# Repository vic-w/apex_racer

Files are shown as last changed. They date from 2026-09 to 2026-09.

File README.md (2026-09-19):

# APEX GT-01 双座公路跑车

当前 CAD、STEP、STL 和 3MF 均已缩为原设计的 **60%**。切片软件保持 **100%** 导入，**不要再缩到 60%**。

侧放打印尺寸约 **119.7 × 32.4 × 56.4 mm**，小于 [A1 mini 的 180 × 180 × 180 mm 成型空间](https://us.store.bambulab.com/products/a1-mini)。3MF 是通用网格文件，不含打印机切片参数。

## 座舱、车窗和尾翼

- 主车身重新绘制为平顺的三次样条曲面，控制机盖与轮拱的高差，避免局部鼓包及深凹槽。前舱和后部的 14 条纵向采样线均无额外波谷；机盖与轮肩最大高差约 **2.12 mm**。
- 车头与车尾向端部渐降，最前、最后的底缘以相切曲线上收，减小厚重的垂直立面。端部中心截面厚度约为车头 **5.9 mm**、车尾 **6.2 mm**；前脸采用单层宽进气口。轮拱与贴床区不随端部一起压扁。此项为外形调整，未进行风阻仿真。
- 两个前大灯分置在车头左右外角，灯带跨越机盖上表面、前脸与侧面，在圆角处连续转折。每侧灯面均实测覆盖这三个面；侧面灯尾位于输出坐标约 **Y=±28.1 mm**。边框投影宽 **0.54 mm**、沿包角三轴凹深 **0.39 mm**，灯罩面凹深 **0.11 mm**；边框和灯罩的高差可在单色打印中保留轮廓，全部与车体连为一体。
- 前后四角改为渐变弧线收拢，纵向退让 **7.2 mm**、横向过渡 **14.4 mm**，保留 **56.4 mm** 的最大车宽。圆角在侧放方向逐层外扩，最大坡度控制为 45°。
- 车顶使用沿车长放样的圆弧截面，前后和横向均有弧度，最高点约 **32.4 mm**。
- 四个轮拱覆盖胎面上方，车轮保持转动间隙；沿胎宽和上部 120° 圆弧采样，壳体最薄约 **1.78 mm**，与胎面径向间隙 **0.9 mm**。
- 座舱后部延长为缓降的溜背曲面，逐渐接入后轮肩部与尾部平台，避免后风挡末端突然下落。
- 侧窗从靠近贴床面的外侧肩部起步，向车顶按约 **45°** 内倾；侧放后也是与热床约 45° 的斜面。中部窗下缘距热床约 **0.5 mm**，上部横向宽度约 **43.4 mm**，兼顾逐层成型和双座比例。
- 前后风挡、门窗和新增后侧小窗扩大了玻璃区域，保留连续的窄 A 柱、B 柱与 C 柱。报告记录各窗凹面之间的最小间距。
- 两侧固定车门带真实门缝和凹槽把手。门缝宽 **0.54 mm**，侧窗凹面和门缝横向切入 **0.48 mm**。
- 尾翼采用有弧度、后掠及向两端收窄的曲面翼型，配合翘起的后缘、短支柱和端板，最高点约 **29.4 mm**。翼面后缘厚 **0.96 mm**，端板与支柱名义厚 **1.2 mm**。端板内侧经 **4.8 mm** 翼展长度渐变连接翼面，避免侧放时突然伸出平板。
- 座舱按两个并排乘员参考包络检查：座位中心间距 **18 mm**、坐垫参考宽 **16.2 mm**，保留躯干、头部和腿部参考尺寸。检查仅用于外观比例，模型内部未制作座椅或驾驶设备，车门不可开启。

预览及 FreeCAD 中的深色玻璃、深色灯框和浅色灯罩是实际几何面的显示配色。单色 STL/3MF 不含透明玻璃或多色材料。预览采用实际 CAD 面的法线，保留真实曲面和特征边界，避免平整面被错误显示成凹陷。

## 前后贴床区域

前保险杠与后轮后方车尾永久加宽，两侧外缘与轮面同处一个侧放打印平面，无需拆除辅助片。

| 检查区域（输出坐标） | 实际平面贴床面积 |
| --- | ---: |
| 车头 X=48 至 60.3 mm | 约 76.3 mm² |
| 车尾 X=-60.6 至 -48 mm，Z<22.8 mm | 约 69.0 mm² |

车尾统计排除了车轮和尾翼，单独检查后保险杠。尾翼端板也接触同一打印平面，具体平面面积及 0.20 mm 首层平均截面积见验证报告。

`print_in_place/bed_contact_preview.png` 中，灰色为整车投影，绿色为车身首层，深灰色为轮组首层，黄色为前后保险杠的平面接触区域。

## 一体打印与检查

模型包含三个互不粘连的实体：一体车身、前轮组、后轮组。同轴左右轮一起转动，前后轴独立转动。

- 只导入 `print_in_place/apex_racer_side_down.stl` 或 `apex_racer.3mf`，保持侧放朝向和三个实体的相对位置。最低点已在 Z=0。
- 输出轴径 **5.4 mm**、孔径 **6.6 mm**，径向间隙 **0.6 mm**；轮胎与轮拱径向间隙 **0.9 mm**。这些间隙随整体同比缩放。
- 可从 0.4 mm 喷嘴、0.16–0.20 mm 层高、3 圈壁、15–20% 填充开始切片。检查首层门缝、轮面纹路和轮组间隙，避免象脚连住活动件。
- 按侧放无支撑目标设计：侧窗约 45°、车顶逐步收拢、前脸开口以 45° 收口，尾翼端板渐变展开，支柱及轮毂也采用斜面。门缝和把手的浅凹槽仍有短距离桥接；关闭支撑后检查这些细节的逐层预览，保持轮轴活动间隙通畅。附着不足时可给保险杠及尾翼端板增加外侧 brim。

`scripts/check_delivery.py` 检查保存的 CAD 实体、两侧大灯在上表面、前脸和侧面的连续覆盖、主曲面平顺性、四角收拢、前后端部厚度及渐薄截面、四轮上方壳体覆盖、后座舱过渡坡度、座舱弧面与宽度、双座参考包络、门缝、前后贴床面、尾翼、打印尺寸及 STL/3MF 一致性。生成脚本检查两根轴完整旋转包络与车身的间隙。

尚未实物试打；几何检查不能保证特定材料和打印机上的免支撑效果及转动手感。

本地 Bambu Studio 2.2.1.60 已使用 A1 mini / 0.4 mm 喷嘴、Generic PLA、0.20 mm 层高、3 圈壁及 15% 填充关闭支撑试切片，共 282 层。报告保存 STL 校验值，确认切片所用的就是当前模型；试切片产生的 G-code 仅用于本地检查。

## 文件与重新生成

- `apex_racer.FCStd`、`apex_racer.step`：60% 尺寸的直立 CAD 模型。
- `apex_racer.3mf`、`print_in_place/apex_racer_side_down.stl`：同尺寸的侧放打印模型。
- `apex_racer_preview.png`：前侧透视、侧视、后侧透视及俯视预览。
- `print_in_place/validation_report.json`：所有尺寸均以输出文件为准。
- `scripts/build_print_in_place.py`：构建、缩放和几何检查。
- `scripts/body_surface.py`：平顺主曲面、四角弧线以及曲面检查。
- `scripts/headlights.py`：环绕前角的前大灯、浅凹边框以及三面连续覆盖检查。
- `scripts/sports_coupe.py`：弧面座舱、窗面、车门、曲面尾翼及乘员参考包络。

代码内部仍使用原始设计坐标，通过 `MODEL_SCALE = 0.6` 整体缩放后输出。`scripts/build_racer.py` 只提供基础几何函数，不要单独运行它覆盖当前模型。

已验证环境为 Windows、FreeCAD 1.0.2 及其自带 Python 3.11；渲染还需要 NumPy、Pillow 和 Windows Arial 字体。在仓库根目录的 PowerShell 中执行：

```powershell
$freecadBin = 'D:\soft\FreeCAD 1.0\bin'
& "$freecadBin\python.exe" scripts/build_print_in_place.py
& "$freecadBin\FreeCADCmd.exe" scripts/export_current_3mf.py
& "$freecadBin\python.exe" scripts/render_racer.py
& "$freecadBin\python.exe" scripts/render_bed_contact.py
Start-Process -FilePath "$freecadBin\freecad.exe" -ArgumentList ('"' + (Join-Path $PWD 'scripts\save_display.FCMacro') + '"') -WindowStyle Hidden -Wait
& "$freecadBin\python.exe" scripts/check_slicing.py --bambu-dir 'D:\soft\Bambu Studio'
& "$freecadBin\python.exe" scripts/package_print.py
& "$freecadBin\python.exe" scripts/check_delivery.py
```

打印压缩包 `apex_racer_print_pack.zip`、中间场景 JSON 和 FreeCAD 自动备份不纳入 Git。如果本地已有压缩包，检查脚本也会验证它与当前打印文件完全一致。

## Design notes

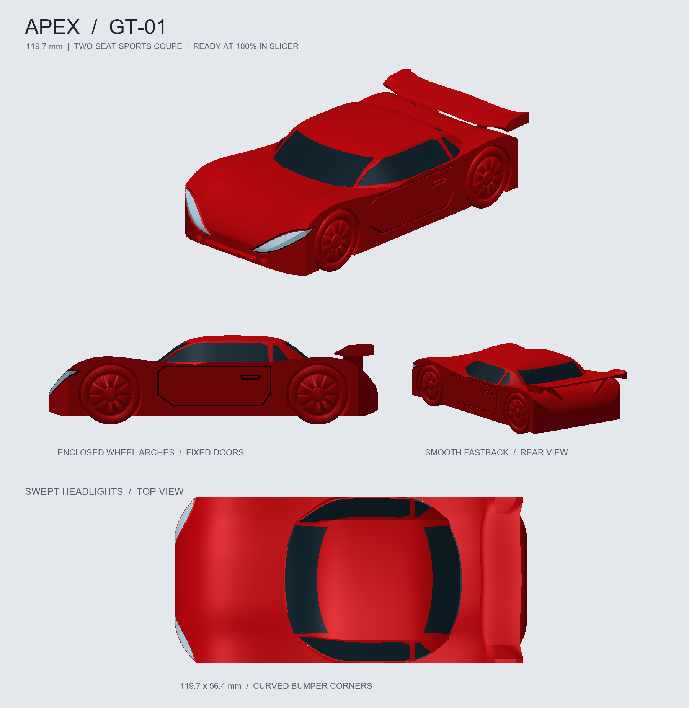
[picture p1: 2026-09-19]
apex_racer_preview.png

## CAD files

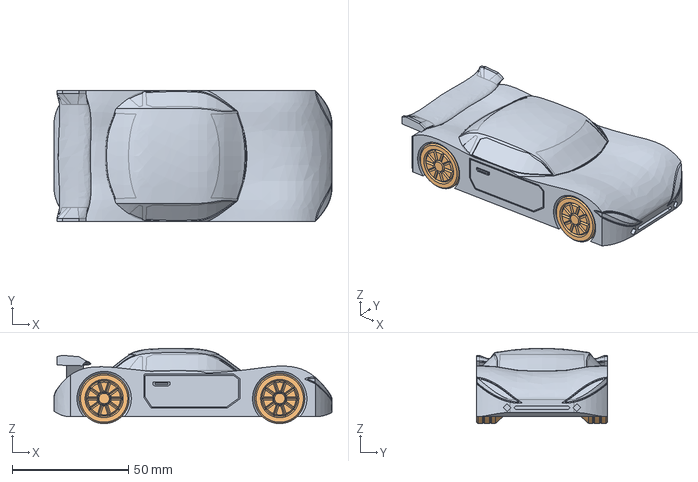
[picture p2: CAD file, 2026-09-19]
apex_racer.step
119.7 x 56.4 x 32.4 mm

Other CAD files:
print_in_place/apex_racer_side_down.stl
apex_racer.3mf
apex_racer.FCStd

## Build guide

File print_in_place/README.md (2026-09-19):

# APEX GT-01 打印说明

模型已经按原设计的 **60%** 输出。导入 `apex_racer_side_down.stl` 时保持 **100%**，**不要再缩小到 60%**。

侧放包围盒约 **119.7 × 32.4 × 56.4 mm**。保持已有朝向，轮轴沿打印 Z 方向、最低点为 Z=0。不要拆开排列车身、前轮组和后轮组，也不要填补轮组间隙。

根目录 `apex_racer.3mf` 为同一模型的通用 3MF，不含特定打印机切片参数。

## 当前造型

主车身重新绘制为连续平顺曲面，轮拱与机盖缓和衔接，前后四角以渐变弧线收拢，消除方正轮廓。最大车宽仍为 56.4 mm。

机盖和车尾向端部逐渐降低，底缘仅在最前、最后一小段平滑上收。端部中心截面厚度约为车头 5.9 mm、车尾 6.2 mm；前脸采用单层宽进气口，轮拱仍完整覆盖胎面上方。

两个前大灯分置在左右外角，灯带从机盖上表面绕过圆角，连续延伸到前脸和侧面。灯框投影宽 0.54 mm、沿包角三轴凹深 0.39 mm，灯罩面凹深 0.11 mm；几何高差形成清晰轮廓，与车体一体打印。预览中的浅色灯罩和深色边框仅为显示配色。

弧面车顶最高约 32.4 mm；侧窗从距热床约 0.5 mm 的外侧肩部起步，以约 45° 向内收拢，上部横向宽度约 43.4 mm。扩大前后风挡并增加后侧小窗，缩窄 A/C 柱。固定车门带 0.54 mm 宽门缝和凹槽把手；车窗与门缝凹深为横向 0.48 mm。曲面尾翼带后掠、收窄翼端、翘起后缘及渐变端板，最高约 29.4 mm。

车门不能开启，封闭车身内未建模座椅。预览中的深色窗面是显示配色，不是透明玻璃或多色打印材料。

四个轮拱均由加高、加宽的车壳覆盖胎面上方，轮胎与轮拱保留活动间隙。座舱后部以延长的溜背曲面逐渐接入后轮肩部和尾部平台。

## 前后附着

前轮前方和后轮后方保留永久贴床区域。输出文件车头平面贴床面积约 **76.3 mm²**，后轮后方车尾约 **69.0 mm²**，分别统计车身本体，不含轮胎和尾翼。

`bed_contact_preview.png` 中，绿色为车身首层，深灰色为轮组首层，黄色为加宽的前后保险杠。尾翼端板也在同一打印平面上。逐层确认前后保险杠和端板均从首层开始，必要时加外侧 brim。

## 切片起点

- 0.4 mm 喷嘴，0.16–0.20 mm 层高，3 圈壁，15–20% 填充。
- 按无支撑侧放设计：45° 侧窗、渐变尾翼端板、45° 支柱及轮毂，前脸开口也改为斜面收口。关闭支撑，逐层检查门缝与把手浅凹槽的短距离桥接。
- 轴孔活动间隙内不要生成支撑；检查象脚和残料是否连接轮组。
- 轴径 5.4 mm、孔径 6.6 mm，径向间隙 0.6 mm；轮胎与轮拱径向间隙 0.9 mm。这些尺寸已经包含整体缩放。

`validation_report.json` 记录实际输出尺寸、有效实体、闭合网格、前后贴床面积、双座参考包络及完整旋转检查。尚未实物试打，几何检查不等同于实物免支撑或转动手感验证。

已用 Bambu Studio 2.2.1.60 的 A1 mini / Generic PLA 配置，按以上参数关闭支撑完成 282 层试切片。报告记录了当前 STL 的校验值及切片结果。

源码和完整构建步骤见仓库根目录 README.md。

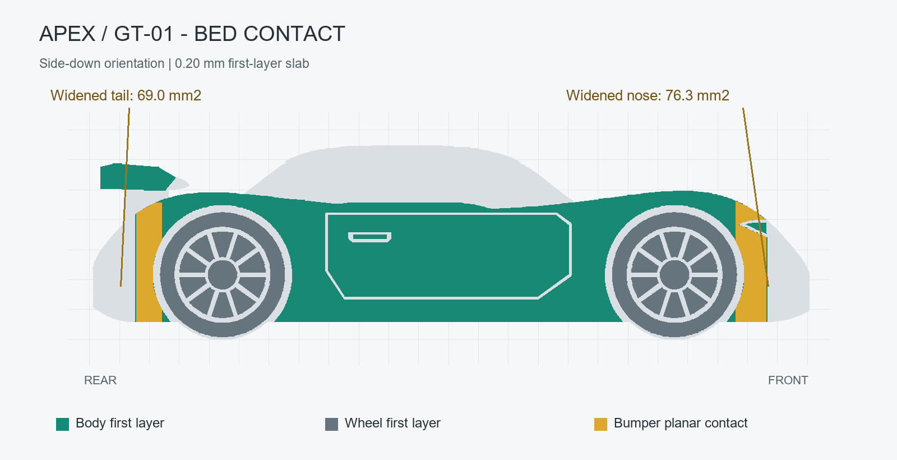
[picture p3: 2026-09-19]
print_in_place/bed_contact_preview.png

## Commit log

2026-09-18 Improve bed adhesion and clean up model repository
    [apex_racer.20260914-before-wheel-texture.3mf, apex_racer.3mf, apex_racer.FCStd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]
2026-09-19 Redesign two-seat coupe for supportless printing at 60 percent scale
    [apex_racer.3mf, apex_racer.FCStd, apex_racer.step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]
2026-09-19 Streamline coupe body with covered wheels and tapered bumpers
    Rebuild the body with a fair spline surface, rounded corners and a smooth rear cabin transition. Lower the nose and tail while preserving wheel clearance and permanent bed contact.
    Update CAD, print meshes, previews and validation reports; verify A1 mini slicing with supports disabled.
    [apex_racer.3mf, apex_racer.FCStd, apex_racer.step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]
2026-09-19 Move headlights to wraparound outer corners
    Place the paired headlights at the left and right front corners, extending each lens across the bonnet, front fascia and side surface.
    Regenerate CAD and print assets, and validate the A1 mini supportless slice, wheel clearance and bed contact.
    [apex_racer.3mf, apex_racer.FCStd, apex_racer.step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]
